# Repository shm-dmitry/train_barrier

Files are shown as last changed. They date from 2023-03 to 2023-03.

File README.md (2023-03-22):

It's a toy for a children :)
I assembled board, its worked.
Known issues:
- schematics/board. I know how to make it better. But current design ok for a toy. I will chabnge it in case of child requested new version :)
- 3D model: train-barrier-cap. But I printed it 5 times, and last version was acceptable, so maybe I will change it later.
- firmware: There are some issue with beeper, I will check it.

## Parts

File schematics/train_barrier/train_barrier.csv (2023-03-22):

Source: | /opt/work-iot/train_barrier/schematics/train_barrier/train_barrier.kicad_sch
Date: | Вт 14 мар 2023 09:53:48
Tool: | Eeschema 7.0.1-3b83917a11~171~ubuntu22.04.1
Generator: | /usr/share/kicad/plugins/bom_csv_grouped_by_value_with_fp.py
Component Count: | 33
Ref | Qnty | Value | Cmp name | Footprint | Description | Vendor | DNP
BT1 | 1 | 9V | Battery_Cell | Connector_Wire:SolderWire-0.5sqmm_1x02_P4.8mm_D0.9mm_OD2.3mm | Single-cell battery
C1 | 1 | 1000 uF | C_Polarized | Capacitor_THT:CP_Radial_D8.0mm_P5.00mm | Polarized capacitor
C2 | 1 | 22 uF | C | Capacitor_SMD:C_0603_1608Metric | Unpolarized capacitor
C3, C4, C5 | 3 | 0.1 uF | C | Capacitor_SMD:C_0603_1608Metric | Unpolarized capacitor
C6 | 1 | 22 uF | C_Polarized | Capacitor_THT:CP_Radial_D8.0mm_P3.50mm | Polarized capacitor
D1 | 1 | DIODE | 1N4001 | Diode_THT:D_5W_P5.08mm_Vertical_AnodeUp | 50V 1A General Purpose Rectifier Diode, DO-41
D2 | 1 | LED_Dual_AKAK | LED_Dual_AKAK | Connector_JST:JST_XH_B4B-XH-A_1x04_P2.50mm_Vertical | Dual LED, cathodes on pins 2 and 4
D3 | 1 | SMAJ5.0CA-TR | ESD9B3.3ST5G | Diode_SMD:D_SMA | ESD protection diode, 3.3Vrwm, SOD-923
H1 | 1 | MountingHole | MountingHole | MountingHole:MountingHole_3.2mm_M3 | Mounting Hole without connection
J1 | 1 | USBASP | Conn_02x05_Odd_Even | Connector_PinHeader_2.54mm:PinHeader_2x05_P2.54mm_Vertical | Generic connector, double row, 02x05, odd/even pin numbering scheme (row 1 odd numbers, row 2 even numbers), script generated (kicad-library-utils/schlib/autogen/connector/)
LS1 | 1 | Speaker_Crystal | Speaker_Crystal | Connector_Wire:SolderWire-0.5sqmm_1x02_P4.6mm_D0.9mm_OD2.1mm | Crystal speaker/transducer
M1 | 1 | Motor_Servo | Motor_Servo | Connector_JST:JST_XH_B3B-XH-A_1x03_P2.50mm_Vertical | Servo Motor (Futaba, HiTec, JR connector)
Q1, Q3, Q6 | 3 | IRLML0030 | IRLML0030 | Package_TO_SOT_SMD:SOT-23 | 5.3A Id, 30V Vds, 27mOhm Rds, N-Channel HEXFET Power MOSFET, SOT-23
Q2, Q4, Q5 | 3 | IRLML5203 | IRLML5203 | Package_TO_SOT_SMD:SOT-23 | -3.0A Id, -30V Vds, 98mOhm Rds, P-Channel HEXFET Power MOSFET, SOT-23
R1, R4, R5, R7, R9 | 5 | 300K | R | Resistor_SMD:R_0805_2012Metric | Resistor
R2 | 1 | 10K | R | Resistor_SMD:R_0805_2012Metric | Resistor
R3 | 1 | 100K | R | Resistor_SMD:R_0805_2012Metric | Resistor
R6, R8 | 2 | 100 | R | Resistor_SMD:R_0805_2012Metric | Resistor
R10 | 1 | 0 | R | Resistor_SMD:R_0805_2012Metric | Resistor
SW1 | 1 | SW_Push_Dual_x2 | SW_Push_Dual_x2 | Connector_JST:JST_XH_B4B-XH-A_1x04_P2.50mm_Vertical | Push button switch, generic, separate symbols, four pins
U1 | 1 | LM2596S | DCDC | Library:DCDC_LM2596
U2 | 1 | ATtiny13A-SS | ATtiny13A-SS | Package_SO:SOIC-8_3.9x4.9mm_P1.27mm | 20MHz, 1kB Flash, 64B SRAM, 64B EEPROM, debugWIRE, SOIC-8

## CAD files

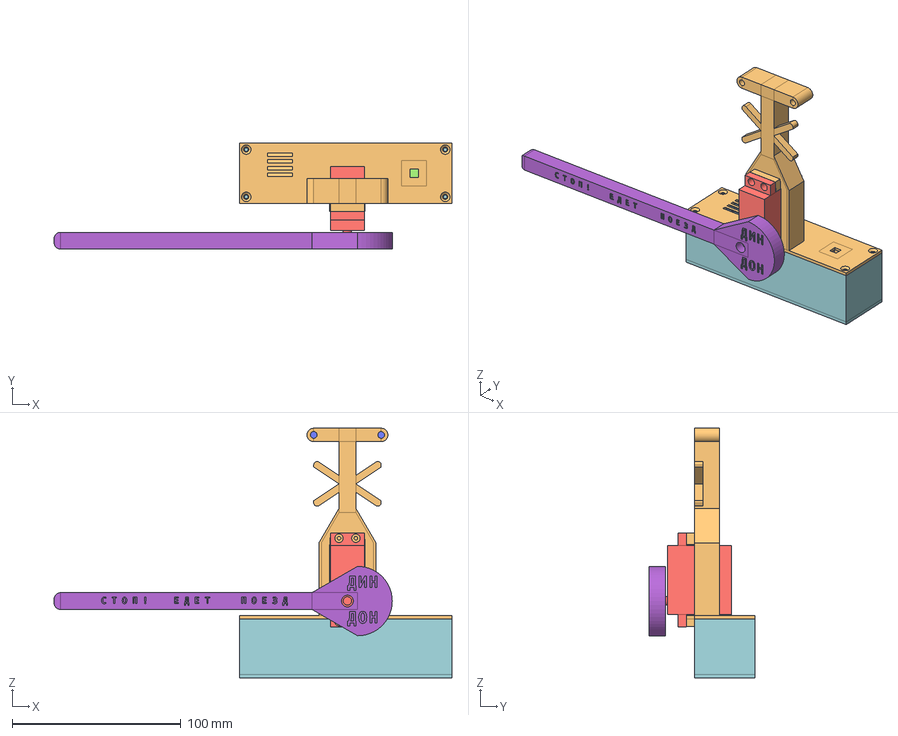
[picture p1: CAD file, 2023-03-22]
3d/train_barrier.FCStd
236.0 x 63.0 x 148.0 mm
board
servo
battery
cup
barrier
wires-cap

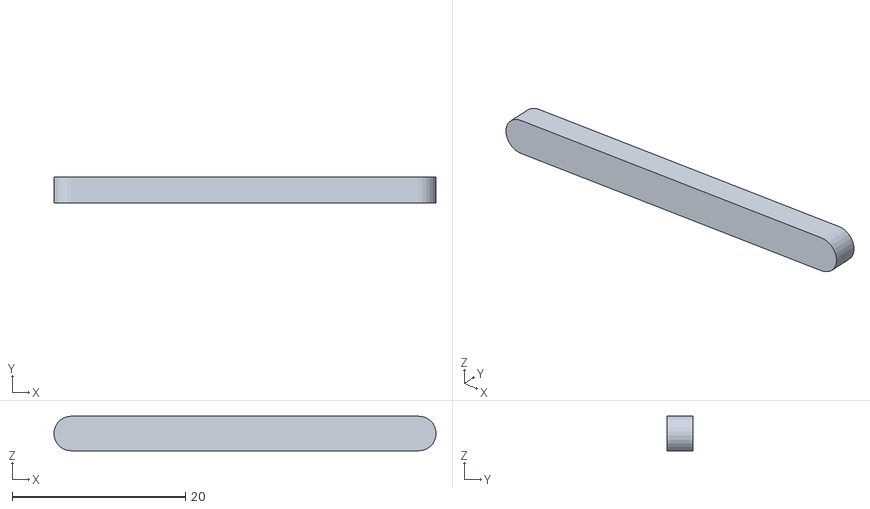
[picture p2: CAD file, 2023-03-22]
3d/train_barrier-wires-cap.stl
44.1 x 3.00 x 4.00

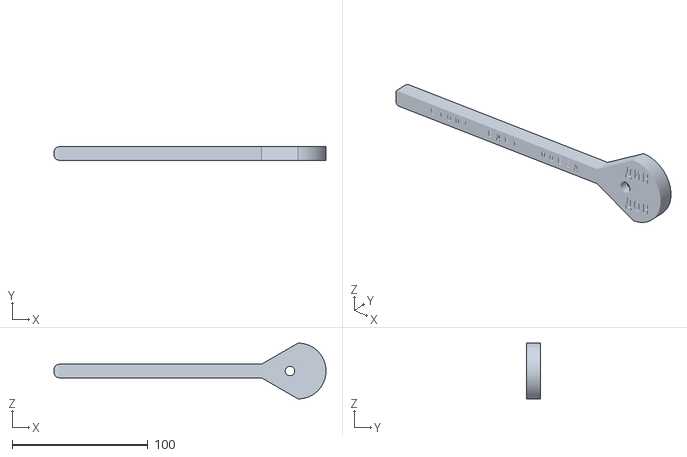
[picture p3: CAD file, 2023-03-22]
3d/train_barrier-barrier.stl
200.6 x 10.0 x 41.2

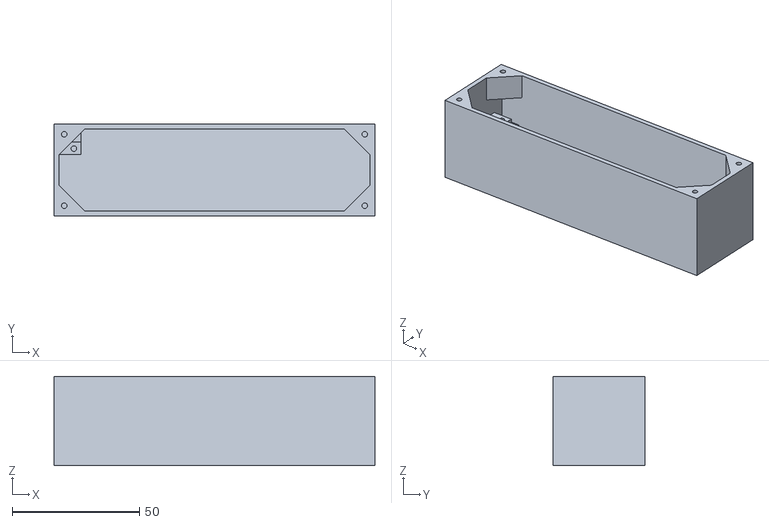
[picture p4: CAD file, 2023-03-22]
3d/train_barrier-box.stl
126.0 x 36.0 x 35.0

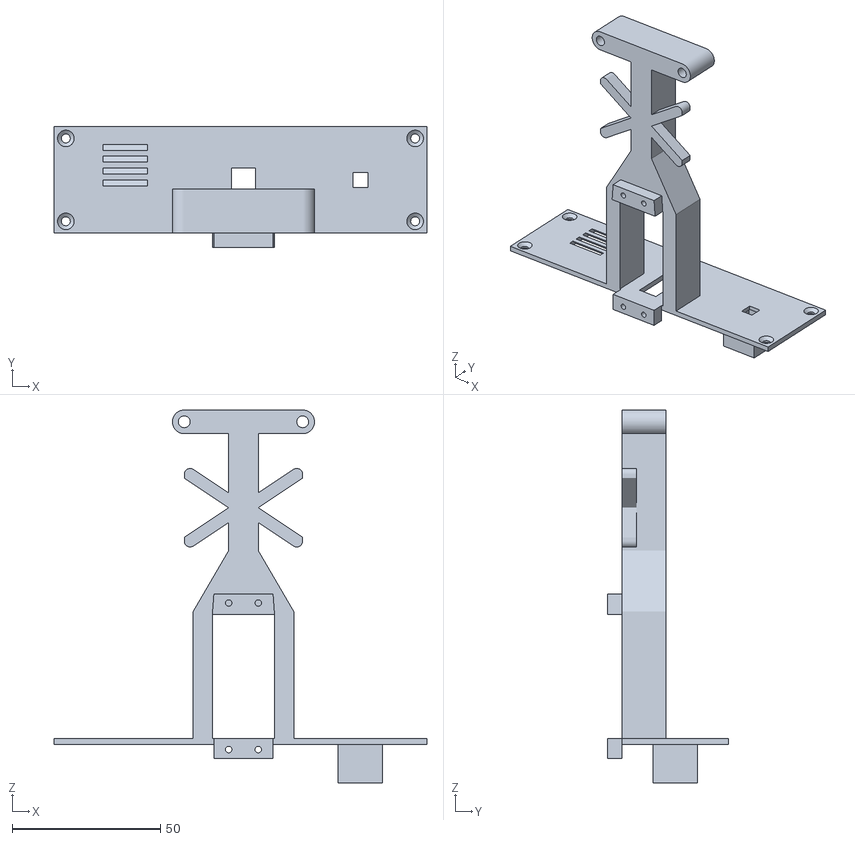
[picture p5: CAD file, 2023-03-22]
3d/train_barrier-cup.stl
126.0 x 40.8 x 126.0

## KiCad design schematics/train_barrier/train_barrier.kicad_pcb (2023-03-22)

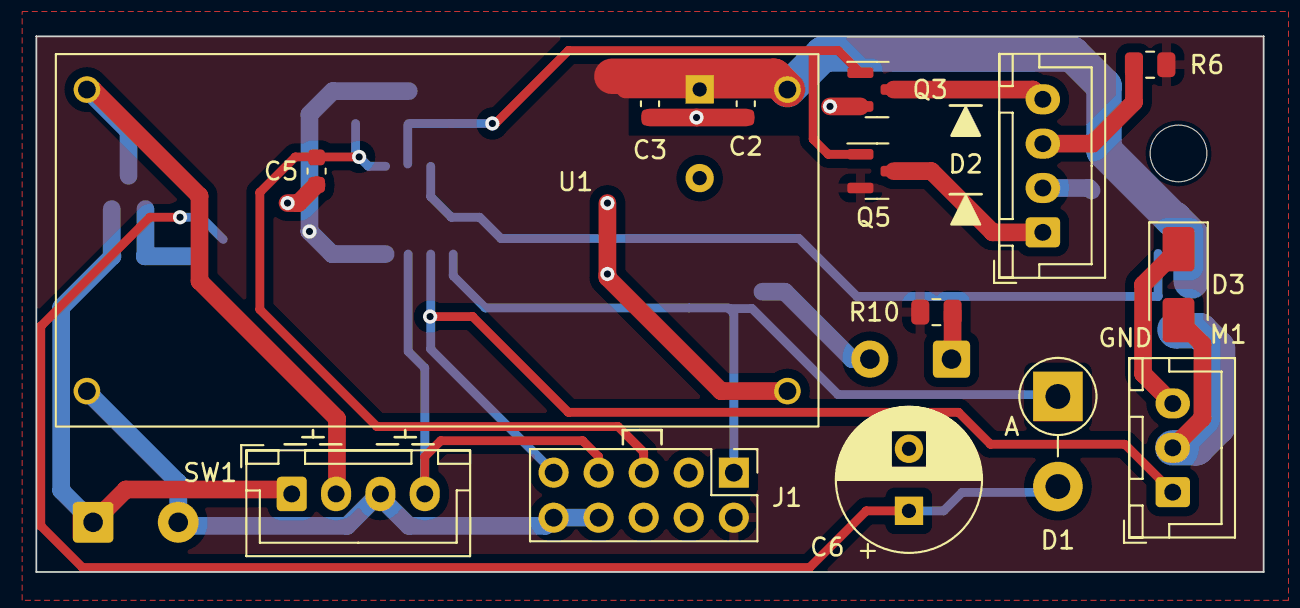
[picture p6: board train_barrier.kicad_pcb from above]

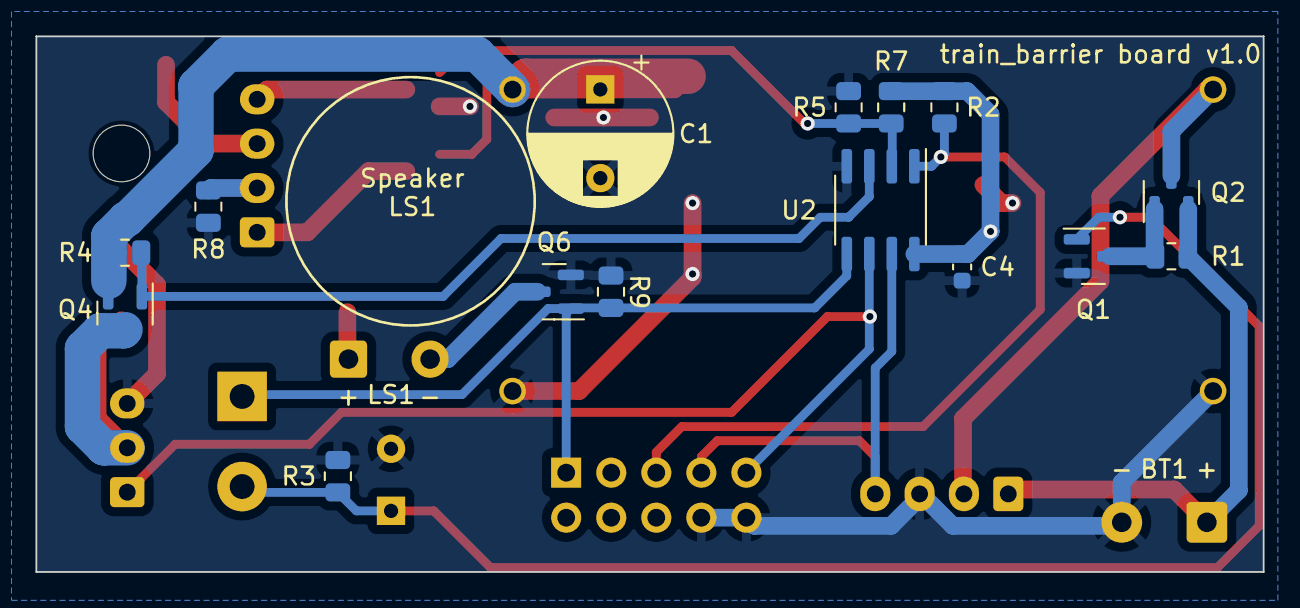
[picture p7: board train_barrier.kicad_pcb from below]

Board: 2 copper layers, 69.2 x 30.2 mm, 33 parts (17 on the bottom side), 19 nets.

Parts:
BT1: 9V; SolderWire-0.5sqmm_1x02_P4.8mm_D0.9mm_OD2.3mm
C1: 1000 uF; CP_Radial_D8.0mm_P5.00mm
C2: 22 uF; C_0603_1608Metric
C3, C4, C5: 0.1 uF; C_0603_1608Metric
C6: 22 uF; CP_Radial_D8.0mm_P3.50mm
D1: DIODE; D_5W_P5.08mm_Vertical_AnodeUp
D2: LED_Dual_AKAK; JST_XH_B4B-XH-A_1x04_P2.50mm_Vertical
D3: SMAJ5.0CA-TR; D_SMA
H1: MountingHole; MountingHole_3.2mm_M3
J1: USBASP; PinHeader_2x05_P2.54mm_Vertical
LS1: Speaker_Crystal; SolderWire-0.5sqmm_1x02_P4.6mm_D0.9mm_OD2.1mm
M1: Motor_Servo; JST_XH_B3B-XH-A_1x03_P2.50mm_Vertical
Q1, Q3, Q6: IRLML0030; SOT-23
Q2, Q4, Q5: IRLML5203; SOT-23
R1, R4, R5, R7, R9: 300K; R_0805_2012Metric
R2: 10K; R_0805_2012Metric
R3: 100K; R_0805_2012Metric
R6, R8: 100; R_0805_2012Metric
R10: 0; R_0805_2012Metric
SW1: SW_Push_Dual_x2; JST_XH_B4B-XH-A_1x04_P2.50mm_Vertical
U1: LM2596S; DCDC_LM2596
U2: ATtiny13A-SS; SOIC-8_3.9x4.9mm_P1.27mm

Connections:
+5V: C1.1, C2.1, C3.1, C4.1, J1.2, Q4.2 (S), Q5.2 (S), R2.2, R4.2, R6.1, R7.2, R10.1, U1.4 (OUT_VCC), U2.8 (VCC)
BUTTON: J1.7, SW1.4 (D), U2.7 (PB2)
GND: BT1.2 (-), C1.2, C2.2, C3.2, C4.2, C5.2, C6.2, D3.1 (A1), J1.8, J1.10, M1.3 (-), Q1.2 (S), Q3.2 (S), Q6.2 (S), R3.1, R5.2, R8.2, R9.2, SW1.3 (C), U1.2 (IN_GND), U1.3 (OUT_GND), U2.4 (GND)
LED: Q3.1 (G), Q5.1 (G), R5.1, R7.1, U2.2 (PB3)
NOISE: D1.1 (K), J1.1, Q6.1 (G), R9.1, U2.5 (PB0)
unnamed: BT1.1 (+), Q2.2 (S), R1.2, SW1.1 (C)
unnamed: D2.1 (A1), Q5.3 (D)
unnamed: D2.2 (K1), R8.1
unnamed: D2.3 (A2), R6.2
unnamed: D2.4 (K2), Q3.3 (D)
unnamed: D3.2 (A2), M1.2 (+), Q4.3 (D)
unnamed: LS1.1, R10.2
unnamed: LS1.2, Q6.3 (D)
unnamed: Q1.3 (D), Q2.1 (G), R1.1
unnamed: Q2.3 (D), SW1.2 (D), U1.1 (IN_VCC)
PWR_EN: C6.1, D1.2 (A), Q1.1 (G), R3.2
RESET: C5.1, J1.5, R2.1, U2.1 (~RESET/PB5)
SERVO_EN: Q4.1 (G), R4.1, U2.3 (PB4)
SERVO_PWM: J1.9, M1.1 (PWM), U2.6 (PB1)

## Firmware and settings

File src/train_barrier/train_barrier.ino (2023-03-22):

#include "noise.h"
#include "servo.h"
#include "leds.h"
#include "button.h"

#define NOINPUT_AUTO_OPEN_DELAY 20000
#define NOINPUT_POWERDOWN_DELAY (NOINPUT_AUTO_OPEN_DELAY + 5000)

uint32_t lastactivity = 0;

void setup() {
  leds_init();
  servo_init();
  noise_init();
  button_init();
}

void loop() {
  uint32_t ms = millis();
  
  if (is_button_pressed(ms)) {
    servo_close_open_invert(ms);
    lastactivity = ms;
  }

  if (ms > lastactivity + NOINPUT_AUTO_OPEN_DELAY) {
    servo_open_now(ms);
  }

  bool closed = servo_is_closed();

  leds_on_main_loop(ms, closed);
  noise_on_main_loop(ms, closed);
  servo_on_main_loop(ms);

  if (ms > lastactivity + NOINPUT_POWERDOWN_DELAY) {
    servo_disable();
    noise_stop();
    while(true) { }; // schematics will power down us few seconds later
  }
}

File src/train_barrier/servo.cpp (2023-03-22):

#include "servo.h"
#include "Arduino.h"

#define SERVO_CONTROL_PIN PB1
#define SERVO_PWR_ON_PIN  PB4

#define SERVO_CLOSE_PERIOD   20
#define SERVO_OPEN_PERIOD    10
#define SERVO_LOW_PERIOD     2000
#define SERVO_WORKING_PERIOD 400

uint8_t servo_high_period  = 0;
uint32_t servo_pulse_change = 0;
uint32_t servo_stop_after   = 0;

void servo_init() {
  pinMode(SERVO_CONTROL_PIN, OUTPUT);
  digitalWrite(SERVO_CONTROL_PIN, LOW);

  pinMode(SERVO_PWR_ON_PIN, OUTPUT);
  digitalWrite(SERVO_PWR_ON_PIN, LOW);

  servo_high_period  = SERVO_CLOSE_PERIOD;
  servo_stop_after   = SERVO_WORKING_PERIOD;
}

void servo_on_main_loop(uint32_t ms) {
  if (ms > servo_stop_after) {
    if (digitalRead(SERVO_CONTROL_PIN) == HIGH) {
      digitalWrite(SERVO_CONTROL_PIN, LOW);
    }
    return;
  }
  
  uint32_t now = micros();

  if (now > servo_pulse_change) {
    if (digitalRead(SERVO_CONTROL_PIN) == HIGH) {
      servo_pulse_change = now + (uint32_t) SERVO_LOW_PERIOD;
      digitalWrite(SERVO_CONTROL_PIN, LOW);
    } else {
      servo_pulse_change = now + (uint32_t) servo_high_period * (uint32_t) 100;
      digitalWrite(SERVO_CONTROL_PIN, HIGH);
    }
  }
}

void servo_close_open_invert(uint32_t ms) {
  servo_stop_after   = ms + SERVO_WORKING_PERIOD;
  servo_high_period  = (servo_high_period == SERVO_CLOSE_PERIOD) ? SERVO_OPEN_PERIOD : SERVO_CLOSE_PERIOD;
}

void servo_open_now(uint32_t ms) {
  if (servo_high_period == SERVO_CLOSE_PERIOD) {
    servo_close_open_invert(ms);
  }
}

bool servo_is_closed() {
  return servo_high_period == SERVO_CLOSE_PERIOD;
}

void servo_disable() {
  digitalWrite(SERVO_PWR_ON_PIN, HIGH);
  digitalWrite(SERVO_CONTROL_PIN, LOW);
}
